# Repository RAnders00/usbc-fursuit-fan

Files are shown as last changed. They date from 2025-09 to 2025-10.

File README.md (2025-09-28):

# usbc-fursuit-fan

This project is a controller for a small PWM-controlled fan for use with a fursuit.

It is:

- Powered by USB Type C power delivery
- Variable-speed
- Fairly compact

More docs to follow :)

## Licensing

- The schematic, PCB and CAD design files are licensed under CC-BY-SA 4.0 (`LICENSE` file)
- The code for the firmware is licensed either under the MIT license or Apache-2.0, at your choosing.

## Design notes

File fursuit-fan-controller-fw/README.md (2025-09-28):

# `fursuit-fan-controller-fw`

This is the firmware to run on the STM32F103C8T6 of this project.

The microcontroller generates a speed control PWM signal for the attached fan. The speed can be selected with the plus and minus buttons. The current level is indicated by an RGB LED.

## Hardware setup

1. Attach an ST-Link programmer to your computer via USB. (Have the necessary drivers installed.)
2. Wire up SWDIO, SWCLK, and GND from the programmer to the board.
3. Power the board via USB Type C.

## Software setup

1. Install Rust (https://rust-lang.org/)
1. `rustup toolchain install thumbv7m-none-eabi`
2. `cargo install flip-link`
3. Install probe-rs by following the instructions at https://probe.rs/docs/getting-started/installation/
4. You might need to install drivers for your ST-Link.

After this, you should be able to see your ST-Link by running:

```bash
probe-rs list
```

The output could look something like this:

```
The following debug probes were found:
[0]: STLink V2 -- 0483:3748: (ST-LINK)
```

## Development workflows

To compile, flash the board and then observe log output:

```bash
# Development
cargo run
# Optimized build
cargo run --production
```

## License

Licensed under either of

- Apache License, Version 2.0 ([LICENSE-APACHE](LICENSE-APACHE) or
  http://www.apache.org/licenses/LICENSE-2.0)

- MIT license ([LICENSE-MIT](LICENSE-MIT) or http://opensource.org/licenses/MIT)

at your option.

### Contribution

Unless you explicitly state otherwise, any contribution intentionally submitted
for inclusion in the work by you, as defined in the Apache-2.0 license, shall be
licensed as above, without any additional terms or conditions.

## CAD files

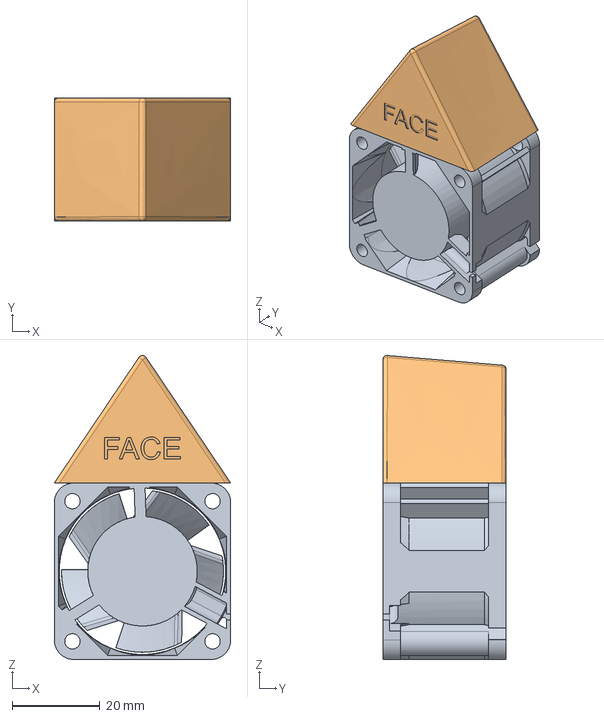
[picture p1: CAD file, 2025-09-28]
CAD/Head Fan Block.step
40.3 x 28.2 x 69.4 mm

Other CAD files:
CAD/Head Fan Block.f3z

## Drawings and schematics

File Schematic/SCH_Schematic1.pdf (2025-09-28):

# USB Type C 12V Input

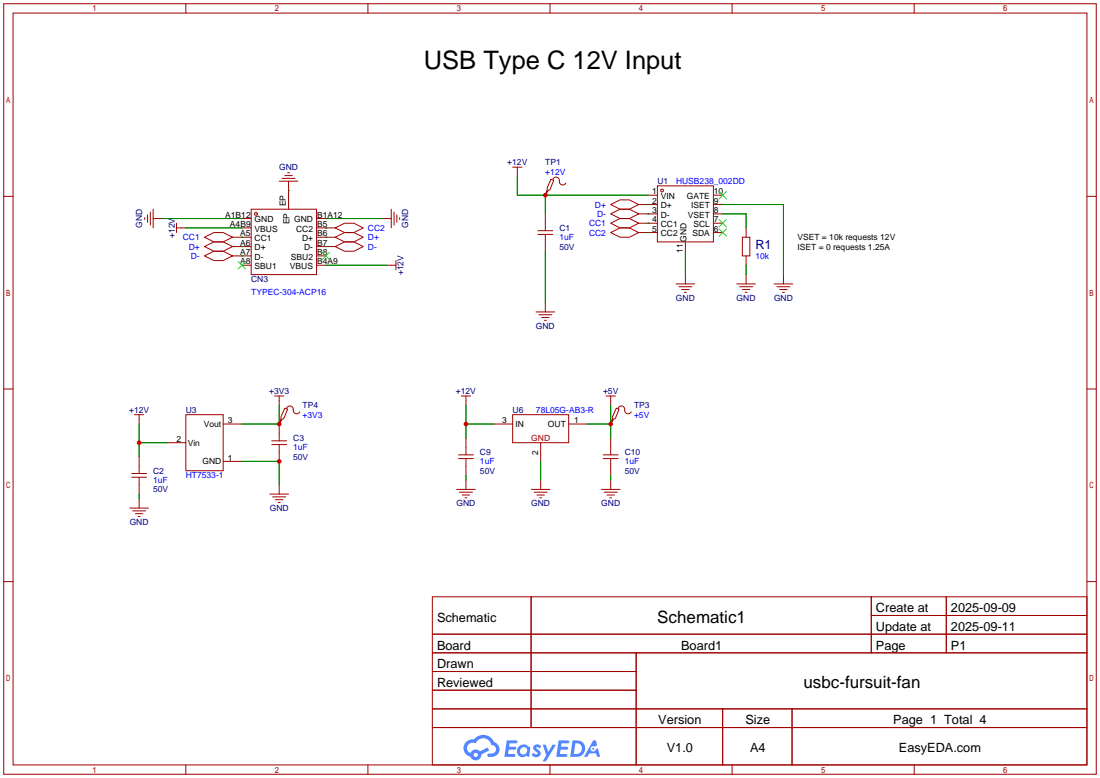
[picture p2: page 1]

Schematic | Schematic1 | Create at | 2025-09-09

Update at | 2025-09-11

Board | Board1 | Page | P1
Drawn | | usbc-fursuit-fan
Reviewed

Version | Size | Page 1 Total 4
V1.0 | A4 | EasyEDA.com

# PWM Generation Microcontroller

# Button Inputs

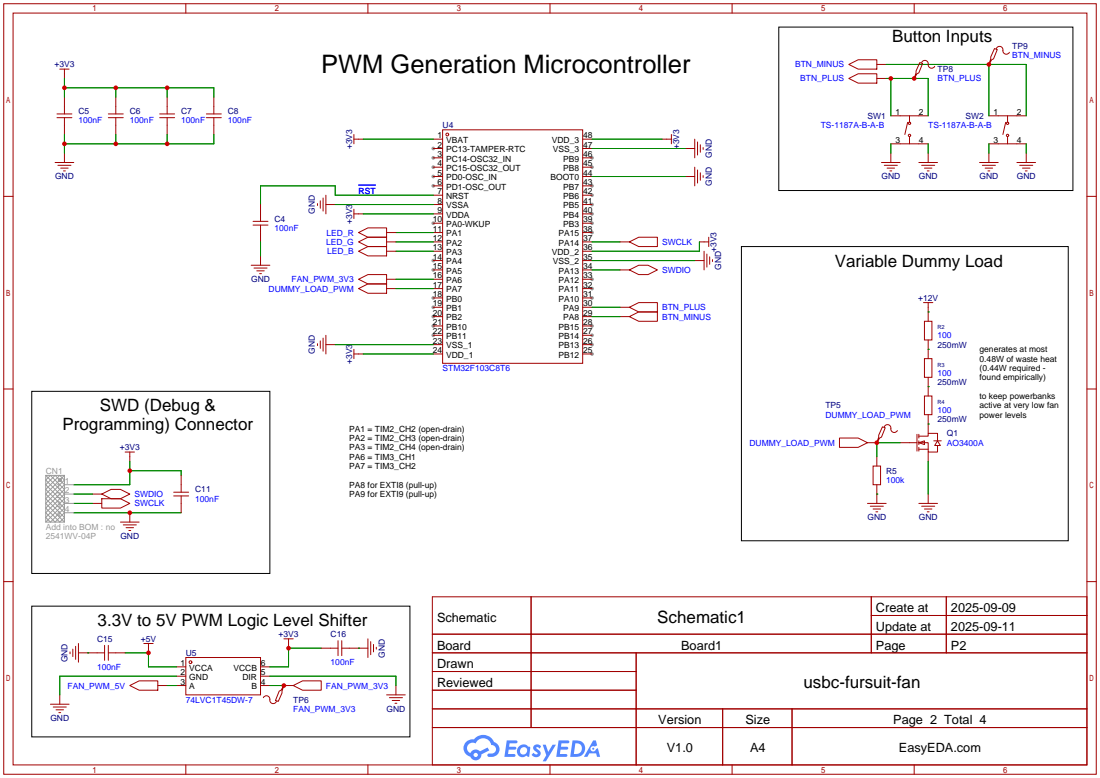
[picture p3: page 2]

generates at most
0.48W of waste heat
(0.44W required -
found empirically)
to keep powerbanks
active at very low fan
power levels

Schematic | Schematic1 | Create at | 2025-09-09

3.3V to 5V PWM Logic Level Shifter

Update at | 2025-09-11

Board | Board1 | Page | P2
Drawn | | usbc-fursuit-fan
Reviewed

# Power Level Indicator (RGB LED)

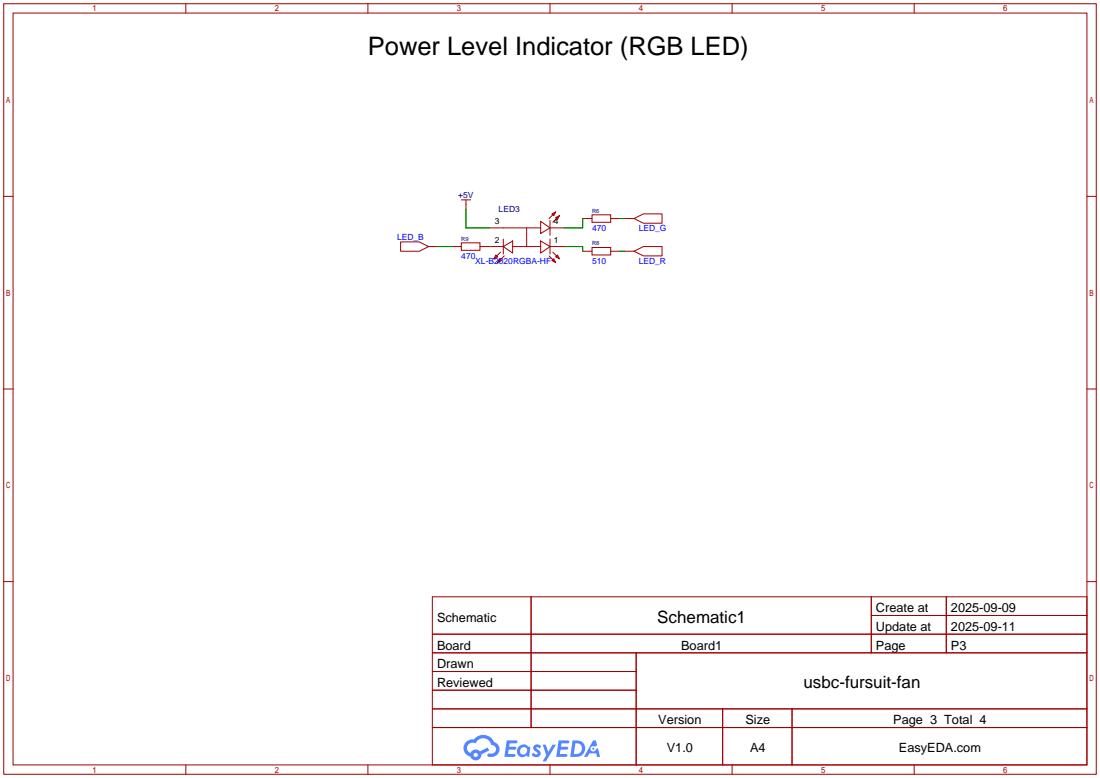
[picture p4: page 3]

Schematic | Schematic1 | Create at | 2025-09-09

Update at | 2025-09-11

Board | Board1 | Page | P3
Drawn | | usbc-fursuit-fan
Reviewed

# Fan output

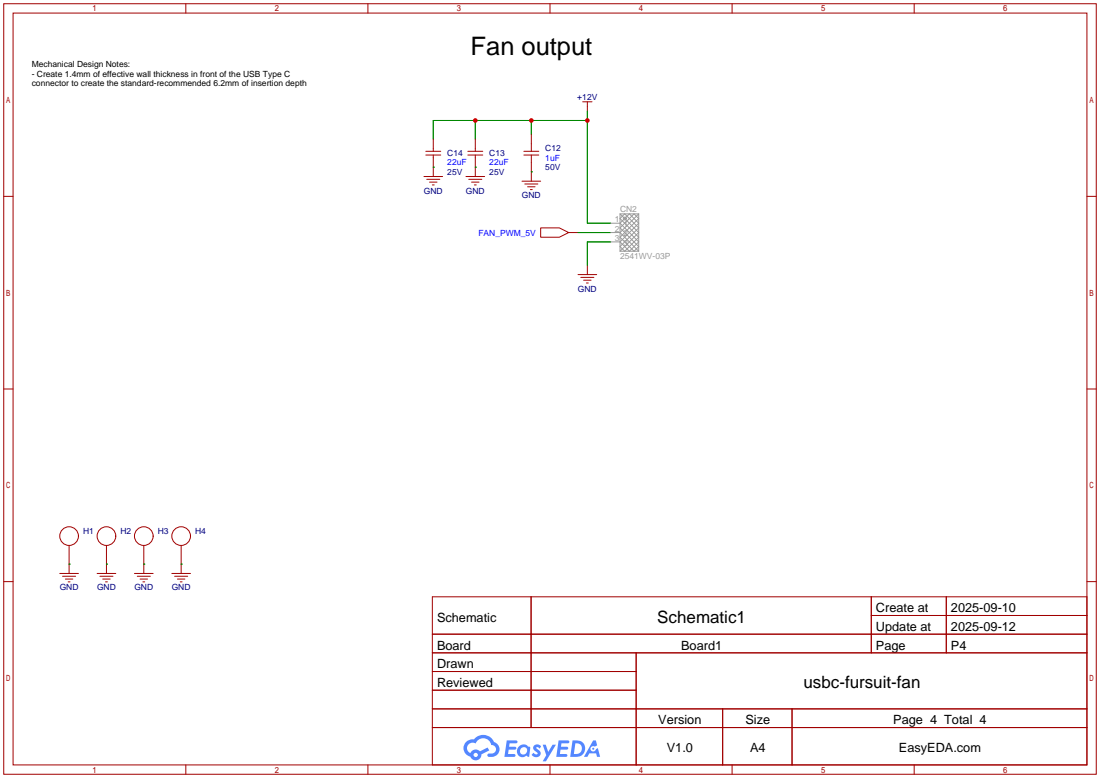
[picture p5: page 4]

Mechanical Design Notes:
- Create 1.4mm of effective wall thickness in front of the USB Type C
connector to create the standard-recommended 6.2mm of insertion depth

Schematic | Schematic1 | Create at | 2025-09-10

Update at | 2025-09-12

Board | Board1 | Page | P4
Drawn | | usbc-fursuit-fan
Reviewed

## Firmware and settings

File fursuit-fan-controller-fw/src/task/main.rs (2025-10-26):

use embassy_futures::select::{Either, select};
use embassy_stm32::{
    Peri,
    gpio::{Level, Output, OutputType, Speed},
    time::khz,
    timer::{
        low_level::{CountingMode, OutputPolarity},
        simple_pwm::{PwmPin, SimplePwmChannels},
    },
};
use embassy_stm32::{
    peripherals::{PA1, PA2, PA3, PA6, PA7, PB0, TIM2, TIM3},
    timer::simple_pwm::SimplePwm,
};
use embassy_sync::{blocking_mutex::raw::CriticalSectionRawMutex, channel::Channel};
use embassy_time::{Duration, Timer};

use crate::persistence::Persistence;

pub static MAIN_TASK_MESSAGES: Channel<CriticalSectionRawMutex, MainTaskMessage, 4> =
    Channel::new();

#[derive(defmt::Format)]
pub enum MainTaskMessage {
    PlusButtonPressed,
    MinusButtonPressed,
}

#[derive(Clone, Copy)]
struct U16Fraction {
    pub numerator: u16,
    pub denominator: u16,
}

impl U16Fraction {
    const fn new(numerator: u16, denominator: u16) -> Self {
        U16Fraction {
            numerator,
            denominator,
        }
    }

    const fn mul(self, other: U16Fraction) -> Self {
        U16Fraction {
            numerator: self.numerator * other.numerator,
            denominator: self.denominator * other.denominator,
        }
    }
}

#[derive(Clone, Copy)]
struct State {
    pub fan: U16Fraction,
    pub dummy: U16Fraction,
    pub r: U16Fraction,
    pub g: U16Fraction,
    pub b: U16Fraction,
}

impl State {
    pub const fn new(fan_pct: u16, dummy_pct: u16, r: u16, g: u16, b: u16) -> Self {
        State {
            fan: U16Fraction::new(fan_pct, 100),
            dummy: U16Fraction::new(dummy_pct, 100),
            r: U16Fraction::new(r, 255),
            g: U16Fraction::new(g, 255),
            b: U16Fraction::new(b, 255),
        }
    }

    pub const fn with_brightness(self, factor: U16Fraction) -> Self {
        State {
            fan: self.fan,
            dummy: self.dummy,
            r: self.r.mul(factor),
            g: self.g.mul(factor),
            b: self.b.mul(factor),
        }
    }
}

static LED_BRIGHTNESS: U16Fraction = U16Fraction::new(2, 10);
const STATES: [State; 11] = [
    State::new(5, 0, 255, 0, 0).with_brightness(LED_BRIGHTNESS), // red
    State::new(10, 0, 255, 40, 0).with_brightness(LED_BRIGHTNESS), // orange?
    State::new(20, 0, 255, 127, 0).with_brightness(LED_BRIGHTNESS), // yellow
    State::new(30, 0, 160, 255, 0).with_brightness(LED_BRIGHTNESS), // light green
    State::new(40, 0, 0, 255, 0).with_brightness(LED_BRIGHTNESS), // deep green
    State::new(50, 0, 90, 0, 255).with_brightness(LED_BRIGHTNESS), // violet
    State::new(60, 0, 0, 255, 255).with_brightness(LED_BRIGHTNESS), // teal
    State::new(70, 0, 0, 0, 255).with_brightness(LED_BRIGHTNESS), // deep blue
    State::new(80, 0, 255, 40, 40).with_brightness(LED_BRIGHTNESS), // salmon
    State::new(90, 0, 255, 0, 255).with_brightness(LED_BRIGHTNESS), // pink
    State::new(100, 0, 255, 255, 255).with_brightness(LED_BRIGHTNESS), // white
];

static INITIAL_STATE_IDX: usize = 5;

static LED_ON_DURATION_AFTER_BUTTON_PRESS: Duration = Duration::from_secs(10);

#[embassy_executor::task]
pub async fn main_task(
    tim2: Peri<'static, TIM2>,
    tim3: Peri<'static, TIM3>,
    pa1: Peri<'static, PA1>,
    pa2: Peri<'static, PA2>,
    pa3: Peri<'static, PA3>,
    pa6: Peri<'static, PA6>,
    pa7: Peri<'static, PA7>,
    pb0: Peri<'static, PB0>,
    mut persistence: Persistence,
) -> ! {
    let r_pin = PwmPin::new(pa1, OutputType::OpenDrain);
    let g_pin = PwmPin::new(pa2, OutputType::OpenDrain);
    let b_pin = PwmPin::new(pa3, OutputType::OpenDrain);

    let tim2_pwm = SimplePwm::new(
        tim2,
        None,
        Some(r_pin),
        Some(g_pin),
        Some(b_pin),
        khz(1),
        CountingMode::default(),
    );

    let SimplePwmChannels {
        ch1: _,
        ch2: mut r,
        ch3: mut g,
        ch4: mut b,
    } = tim2_pwm.split();

    r.set_polarity(OutputPolarity::ActiveLow);
    g.set_polarity(OutputPolarity::ActiveLow);
    b.set_polarity(OutputPolarity::ActiveLow);

    r.set_duty_cycle_fully_off();
    g.set_duty_cycle_fully_off();
    b.set_duty_cycle_fully_off();

    r.enable();
    g.enable();
    b.enable();

    let fan_pwm_pin = PwmPin::new(pa6, OutputType::PushPull);
    let dummy_load_pwm_pin = PwmPin::new(pa7, OutputType::PushPull);

    let tim3_pwm = SimplePwm::new(
        tim3,
        Some(fan_pwm_pin),
        Some(dummy_load_pwm_pin),
        None,
        None,
        khz(25),
        CountingMode::default(),
    );

    let SimplePwmChannels {
        ch1: mut fan,
        ch2: mut dummy_load,
        ch3: _,
        ch4: _,
    } = tim3_pwm.split();

    let load_enable = Output::new(pb0, Level::High, Speed::Low);
    core::mem::forget(load_enable); // to prevent PB0 from being reset to being an input again

    fan.set_duty_cycle_fully_off();
    dummy_load.set_duty_cycle_fully_off();

    fan.enable();
    dummy_load.enable();

    let mut state_idx: usize = persistence.load_state().await.unwrap_or(INITIAL_STATE_IDX);
    let mut led_turn_off_timer: Option<Timer> =
        Some(Timer::after(LED_ON_DURATION_AFTER_BUTTON_PRESS));

    loop {
        let current_state = STATES[state_idx];
        defmt::info!(
            "Now on state {} ({}% fan, {}% dummy)",
            state_idx,
            100 * current_state.fan.numerator / current_state.fan.denominator,
            100 * current_state.dummy.numerator / current_state.dummy.denominator,
        );

        fan.set_duty_cycle_fraction(current_state.fan.numerator, current_state.fan.denominator);
        dummy_load.set_duty_cycle_fraction(
            current_state.dummy.numerator,
            current_state.dummy.denominator,
        );

        if led_turn_off_timer.is_some() {
            r.set_duty_cycle_fraction(current_state.r.numerator, current_state.r.denominator);
            g.set_duty_cycle_fraction(current_state.g.numerator, current_state.g.denominator);
            b.set_duty_cycle_fraction(current_state.b.numerator, current_state.b.denominator);
        } else {
            r.set_duty_cycle_fully_off();
            g.set_duty_cycle_fully_off();
            b.set_duty_cycle_fully_off();
        }

        let event = if let Some(timer) = &mut led_turn_off_timer {
            select(MAIN_TASK_MESSAGES.receive(), timer).await
        } else {
            Either::First(MAIN_TASK_MESSAGES.receive().await)
        };

        match event {
            Either::First(MainTaskMessage::PlusButtonPressed) => {
                defmt::info!("Plus button was pressed");
                if (state_idx + 1) < STATES.len() {
                    state_idx += 1;
                    persistence.save_state(state_idx).await;
                }
                led_turn_off_timer = Some(Timer::after(LED_ON_DURATION_AFTER_BUTTON_PRESS));
            }
            Either::First(MainTaskMessage::MinusButtonPressed) => {
                defmt::info!("Minus button was pressed");
                if state_idx >= 1 {
                    state_idx -= 1;
                    persistence.save_state(state_idx).await;
                }
                led_turn_off_timer = Some(Timer::after(LED_ON_DURATION_AFTER_BUTTON_PRESS));
            }
            Either::Second(()) => {
                defmt::info!("Turning off the LED");
                // clear timer
                led_turn_off_timer = None;
            }
        }
    }
}

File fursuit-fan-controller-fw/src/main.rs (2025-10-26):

#![no_main]
#![no_std]

use cortex_m_rt::entry;
use fursuit_fan_controller_fw::{
    self as _,
    persistence::Persistence,
    task::{self},
}; // global logger + panicking-behavior + memory layout

use defmt::info;
use embassy_executor::Executor;
use embassy_stm32::{
    Config, adc, bind_interrupts,
    peripherals::ADC1,
    rcc::{ADCPrescaler, APBPrescaler, Pll, PllMul, PllPreDiv, PllSource, Sysclk},
};
use static_cell::StaticCell;

static EXECUTOR: StaticCell<Executor> = StaticCell::new();

bind_interrupts!(struct Irqs {
    ADC1_2 => adc::InterruptHandler<ADC1>;
});

#[entry]
fn main() -> ! {
    let mut config = Config::default();
    {
        // HSI = 8 MHz
        config.rcc.hsi = true;
        config.rcc.hse = None;

        // 8 MHz / 2 (fixed) * 16 = 64 MHz
        config.rcc.pll = Some(Pll {
            src: PllSource::HSI,
            prediv: PllPreDiv::DIV2,
            mul: PllMul::MUL16,
        });

        // SYSCLK is the 64 MHz of the PLL
        config.rcc.sys = Sysclk::PLL1_P;

        // APB1 runs at 64 MHz (max would be 72 MHz),
        // APB2 at 32 MHz (max would be 32 MHz)
        config.rcc.apb1_pre = APBPrescaler::DIV2;
        config.rcc.apb2_pre = APBPrescaler::DIV1;

        // Makes the ADCs run at 8 MHz
        // (Divides the APB2 clock)
        config.rcc.adc_pre = ADCPrescaler::DIV8;
    }

    let p = embassy_stm32::init(config);
    info!(
        "{} {} running",
        env!("CARGO_PKG_NAME"),
        env!("CARGO_PKG_VERSION")
    );

    let executor = EXECUTOR.init(Executor::new());
    executor.run(|spawner| {
        let persistence = Persistence::new(p.FLASH);

        defmt::unwrap!(spawner.spawn(task::button_poller(p.PA9, p.PA8)));
        defmt::unwrap!(spawner.spawn(task::main_task(
            p.TIM2,
            p.TIM3,
            p.PA1,
            p.PA2,
            p.PA3,
            p.PA6,
            p.PA7,
            p.PB0,
            persistence
        )));
    });
}

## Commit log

2025-10-22 Introduce CC line voltage detection for Board v2
2025-10-23 make all stages 0 dummy for v2
2025-10-23 prototype persistence
2025-10-26 Remove CC detection since we always draw < 500 mA
